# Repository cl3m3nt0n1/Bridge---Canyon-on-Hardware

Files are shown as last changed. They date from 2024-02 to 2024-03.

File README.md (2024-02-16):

# Bridge---Canyon-on-Hardware
Welcome to Bridge, the hardware adaptation of Canyon, a convolution reverb plugin. This project utilizes ELK Audio OS and the Raspberry Pi Compute Module 4, featuring three custom-designed boards (1 main board and 2 IO boards). We created this project as the foundation for a complete OpenSource Audio FX Pedal based on community's resources. 

## Overview
Bridge extends Canyon's convolution reverb into the physical realm, combining the power of ELK Audio OS/HifiBerry DAC+ADC and Raspberry Pi Compute Module 4 for a robust audio FX solution.

## Features
- **Convolution Reverb:** Achieve realistic and immersive reverb effects through Canyon.
- **Custom Hardware:** Three boards - 1 main and 2 IO boards - designed for modularity and reusability.
- **ELK Audio OS:** Leverage the efficiency of ELK Audio OS for real-time audio processing.

## Hardware
Bridge comprises the following custom-designed boards:

1. **Main Board:**
   - GPIO/HAT Connector
   - SPI Screen Connector for a [480*320 ILI9488 based screen]([url](https://www.amazon.fr/gp/product/B08NV6SNYH/ref=ppx_yo_dt_b_asin_title_o00_s00?ie=UTF8&psc=1))
   - Raspberry Pi Compute Module 4
   - ATMega328p with ICSP connector for IO management

2. **IO Boards (x2):**
   - Pots and Switches for massive fun
   - Rotary encoder

## Software
Bridge relies on serveral pieces of sotware to run :
1. **ATMega328p:**
  - Potentiometer values conversion
  - Screen management
  - Serial communication with CM4
2. **Compute Module 4:**
  - Running ELK Audio OS for real-time audio processing
  - IO management
  - OSC
  - Serial Communication with ATMega328p

## Contributing
We welcome and encourage contributions to enhance Bridge! If you have ideas, bug fixes, or new features, please open an issue or submit a pull request.

## License
The software contained in this project is licensed under the GPL3 license. The hardware is licensed under the Creative Commons v4.0.

Happy coding with Bridge!

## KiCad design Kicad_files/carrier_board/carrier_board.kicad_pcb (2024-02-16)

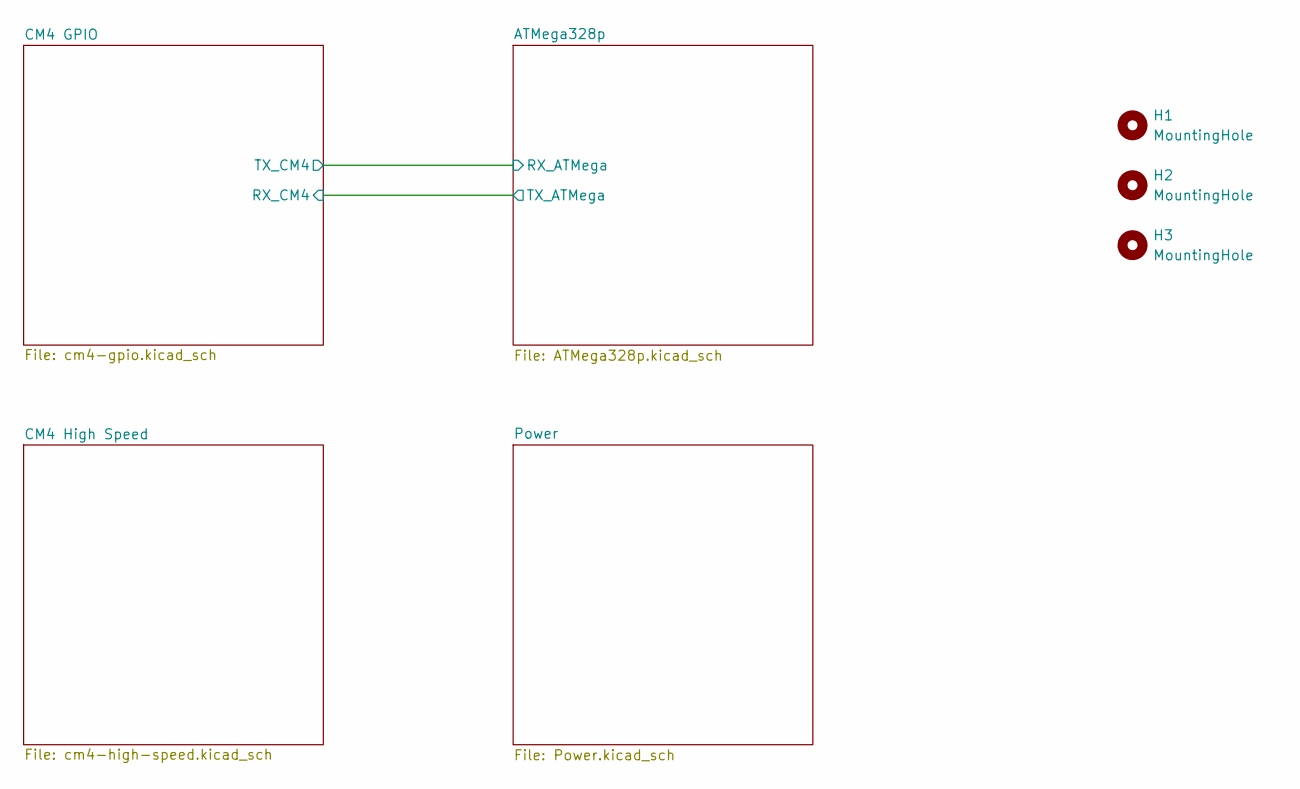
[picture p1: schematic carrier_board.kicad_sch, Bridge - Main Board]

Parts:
H1, H2, H3: MountingHole; MountingHole_2.2mm_M2

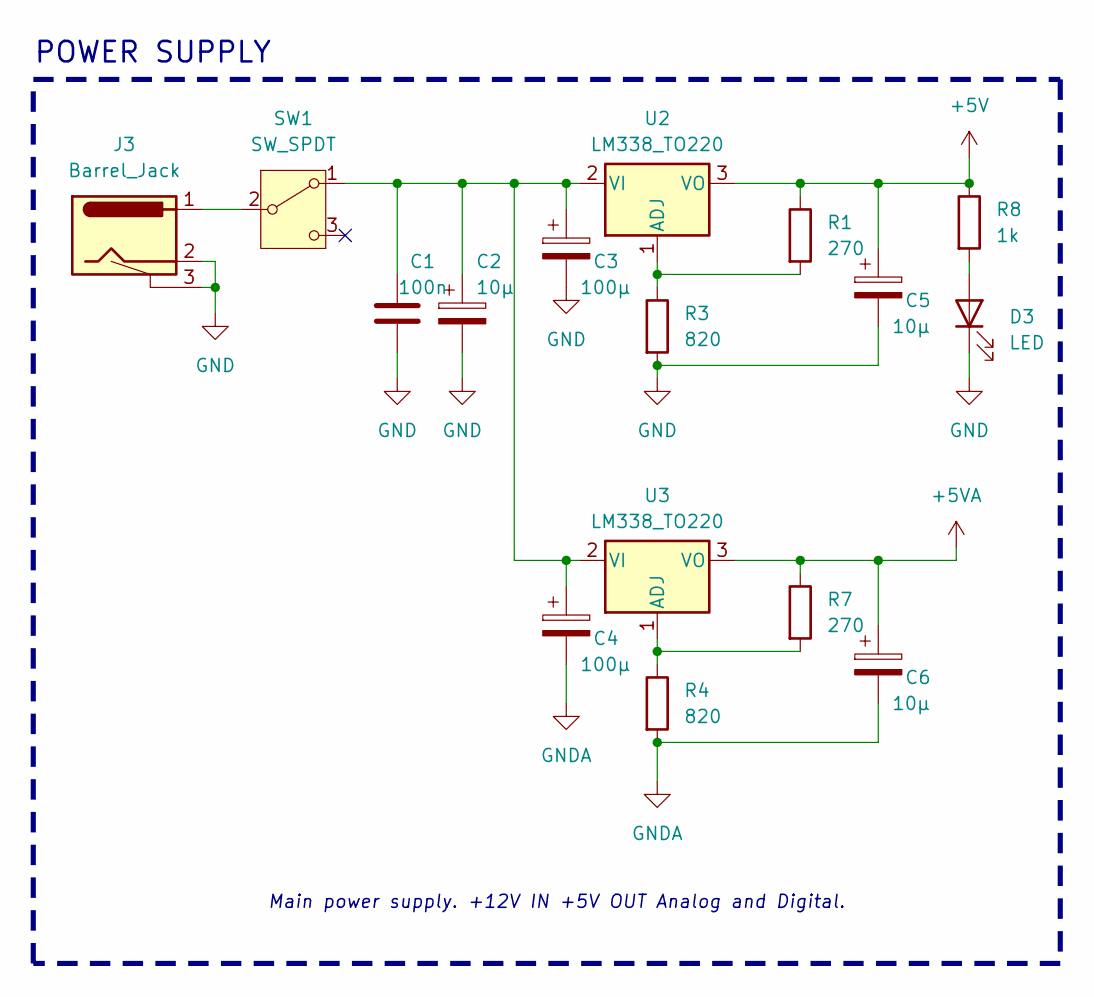
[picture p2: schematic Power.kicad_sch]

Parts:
C1: 100n; C_0402_1005Metric
C2, C5, C6: 10µ; CAPMP3216X180N
C3, C4: 100µ; C_1812_4532Metric
D3: LED; LED_D3.0mm
J3: Barrel_Jack; BarrelJack_Horizontal
R1, R7: 270; R_0603_1608Metric
R3, R4: 820; R_0603_1608Metric
R8: 1k; R_0402_1005Metric
SW1: SW_SPDT; SW_Push_1P2T_Vertical_E-Switch_800UDP8P1A1M6
U2, U3: LM338_TO220; TO-220-3_Vertical

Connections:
+5V: C5.1, R1.1, R8.1, U2.3 (VO); also elsewhere on the board
+5VA: C6.1, R7.1, U3.3 (VO); also elsewhere on the board
GND: C1.2, C2.2, C3.2, C5.2, D3.1 (K), J3.2, J3.3, R3.2; also elsewhere on the board
GNDA: C4.2, C6.2, R4.2; also elsewhere on the board
unnamed: D3.2 (A), R8.2
unnamed: C1.1, C2.1, C3.1, C4.1, SW1.1 (A), U2.2 (VI), U3.2 (VI)
unnamed: J3.1, SW1.2 (B)
unnamed: R1.2, R3.1, U2.1 (ADJ)
unnamed: R4.1, R7.2, U3.1 (ADJ)

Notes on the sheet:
POWER SUPPLY
Main power supply. +12V IN +5V OUT Analog and Digital.

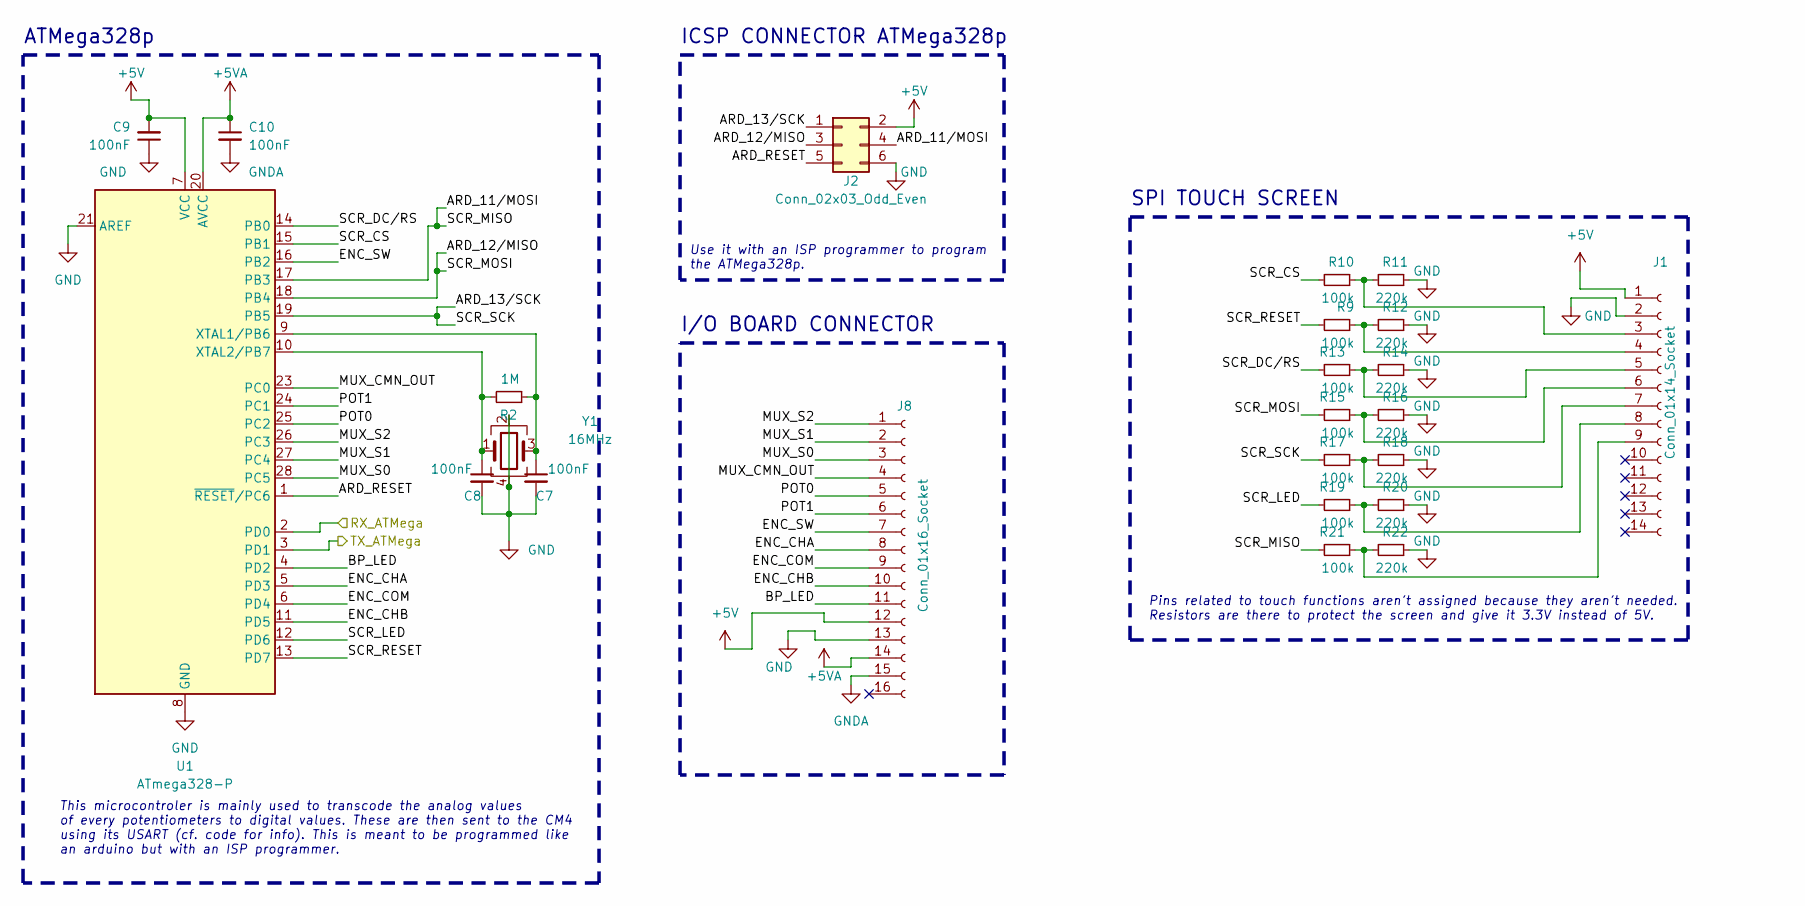
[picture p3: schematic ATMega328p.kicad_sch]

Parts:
C7, C8, C9, C10: 100nF; C_0402_1005Metric
J1: Conn_01x14_Socket; PinSocket_1x14_P2.54mm_Vertical
J2: Conn_02x03_Odd_Even; PinHeader_2x03_P2.00mm_Vertical
J8: Conn_01x16_Socket; Hirose_FH12-16S-0.5SH_1x16-1MP_P0.50mm_Horizontal
R2: 1M; R_0402_1005Metric
R9, R10, R13, R15, R17, R19, R21: 100k; R_0402_1005Metric
R11, R12, R14, R16, R18, R20, R22: 220k; R_0603_1608Metric
U1: ATmega328-P; DIP-28_W7.62mm
Y1: 16MHz; Crystal_SMD_3225-4Pin_3.2x2.5mm

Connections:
+5V: C9.2, J1.1, J2.2, J8.12, U1.7 (VCC); also elsewhere on the board
+5VA: C10.1, J8.14, U1.20 (AVCC); also elsewhere on the board
/ATMega328p/ARD_11/MOSI: J2.4, R21.1, U1.17 (PB3)
/ATMega328p/ARD_12/MISO: J2.3, R15.1, U1.18 (PB4)
/ATMega328p/ARD_13/SCK: J2.1, R17.1, U1.19 (PB5)
/ATMega328p/ARD_RESET: J2.5, U1.1 (~RESET/PC6)
/ATMega328p/BP_LED: J8.11, U1.4 (PD2)
/ATMega328p/ENC_CHA: J8.8, U1.5 (PD3)
/ATMega328p/ENC_CHB: J8.10, U1.11 (PD5)
/ATMega328p/ENC_COM: J8.9, U1.6 (PD4)
/ATMega328p/ENC_SW: J8.7, U1.16 (PB2)
/ATMega328p/MUX_CMN_OUT: J8.4, U1.23 (PC0)
/ATMega328p/MUX_S0: J8.3, U1.28 (PC5)
/ATMega328p/MUX_S1: J8.2, U1.27 (PC4)
/ATMega328p/MUX_S2: J8.1, U1.26 (PC3)
/ATMega328p/POT0: J8.5, U1.25 (PC2)
/ATMega328p/POT1: J8.6, U1.24 (PC1)
/ATMega328p/SCR_CS: R10.1, U1.15 (PB1)
/ATMega328p/SCR_DC/RS: R13.1, U1.14 (PB0)
/ATMega328p/SCR_LED: R19.1, U1.12 (PD6)
/ATMega328p/SCR_RESET: R9.1, U1.13 (PD7)
/CM4 GPIO/GPIO14: U1.2 (PD0); also elsewhere on the board
/CM4 GPIO/GPIO15: U1.3 (PD1); also elsewhere on the board
GND: C7.2, C8.2, C9.1, J1.2, J2.6, J8.13, R11.2, R12.2, R14.2, R16.2, R18.2, R20.2, R22.2, U1.8 (GND), U1.21 (AREF), U1.22 (GND), Y1.2, Y1.4; also elsewhere on the board
GNDA: C10.2, J8.15; also elsewhere on the board
unnamed: J1.3, R10.2, R11.1
unnamed: J1.4, R9.2, R12.1
unnamed: J1.5, R13.2, R14.1
unnamed: J1.6, R15.2, R16.1
unnamed: J1.7, R17.2, R18.1
unnamed: J1.8, R19.2, R20.1
unnamed: J1.9, R21.2, R22.1
unnamed: C7.1, R2.1, U1.9 (XTAL1/PB6), Y1.3
unnamed: C8.1, R2.2, U1.10 (XTAL2/PB7), Y1.1

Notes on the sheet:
I/O BOARD CONNECTOR
This microcontroler is mainly used to transcode the analog values of every potentiometers to digital values. These are then sent to the CM4 using its USART (cf. code for info). This is meant to be programmed like an arduino but with an ISP programmer.
Use it with an ISP programmer to program the ATMega328p.
SPI TOUCH SCREEN
ICSP CONNECTOR ATMega328p
ATMega328p
Pins related to touch functions aren't assigned because they aren't needed. Resistors are there to protect the screen and give it 3.3V instead of 5V.

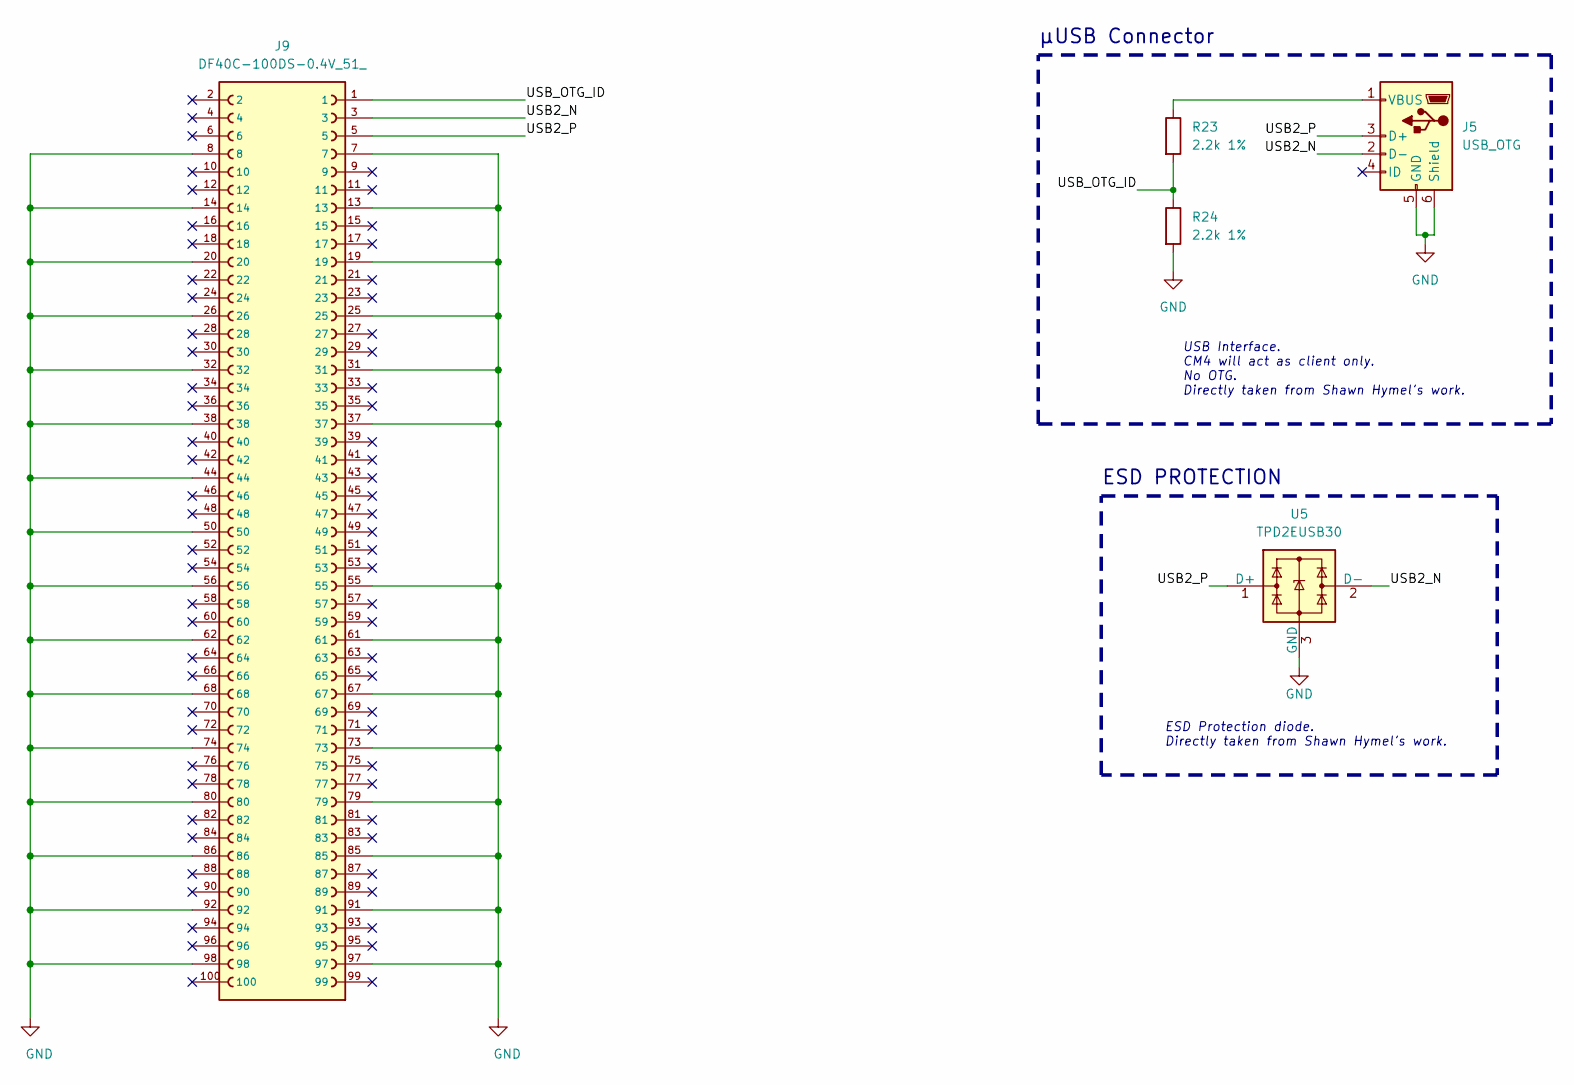
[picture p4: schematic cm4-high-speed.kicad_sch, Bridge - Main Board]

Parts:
J5: USB_OTG; USB_Micro-B_EDAC_UCON00686
J9: DF40C-100DS-0.4V_51_; HIROSE_DF40C-100DS-0.4V_51_; PARTREV Oct.1.2023
R23, R24: 2.2k 1%; R_0402_1005Metric
U5: TPD2EUSB30; Texas_DRT-3

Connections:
/CM4 High Speed/USB2_N: J5.2 (D-), J9.3, U5.2 (D-)
/CM4 High Speed/USB2_P: J5.3 (D+), J9.5, U5.1 (D+)
/CM4 High Speed/USB_OTG_ID: J9.1, R23.2, R24.1
GND: J5.5 (GND), J5.6 (Shield), J9.7, J9.8, J9.13, J9.14, J9.19, J9.20, J9.25, J9.26, J9.31, J9.32, J9.37, J9.38, J9.44, J9.50, J9.55, J9.56, J9.61, J9.62, J9.67, J9.68, J9.73, J9.74, J9.79, J9.80, J9.85, J9.86, J9.91, J9.92, J9.97, J9.98, R24.2, U5.3 (GND); also elsewhere on the board
unnamed: J5.1 (VBUS), R23.1

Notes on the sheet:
µUSB Connector
ESD PROTECTION
USB Interface. CM4 will act as client only. No OTG. Directly taken from Shawn Hymel's work.
ESD Protection diode. Directly taken from Shawn Hymel's work.

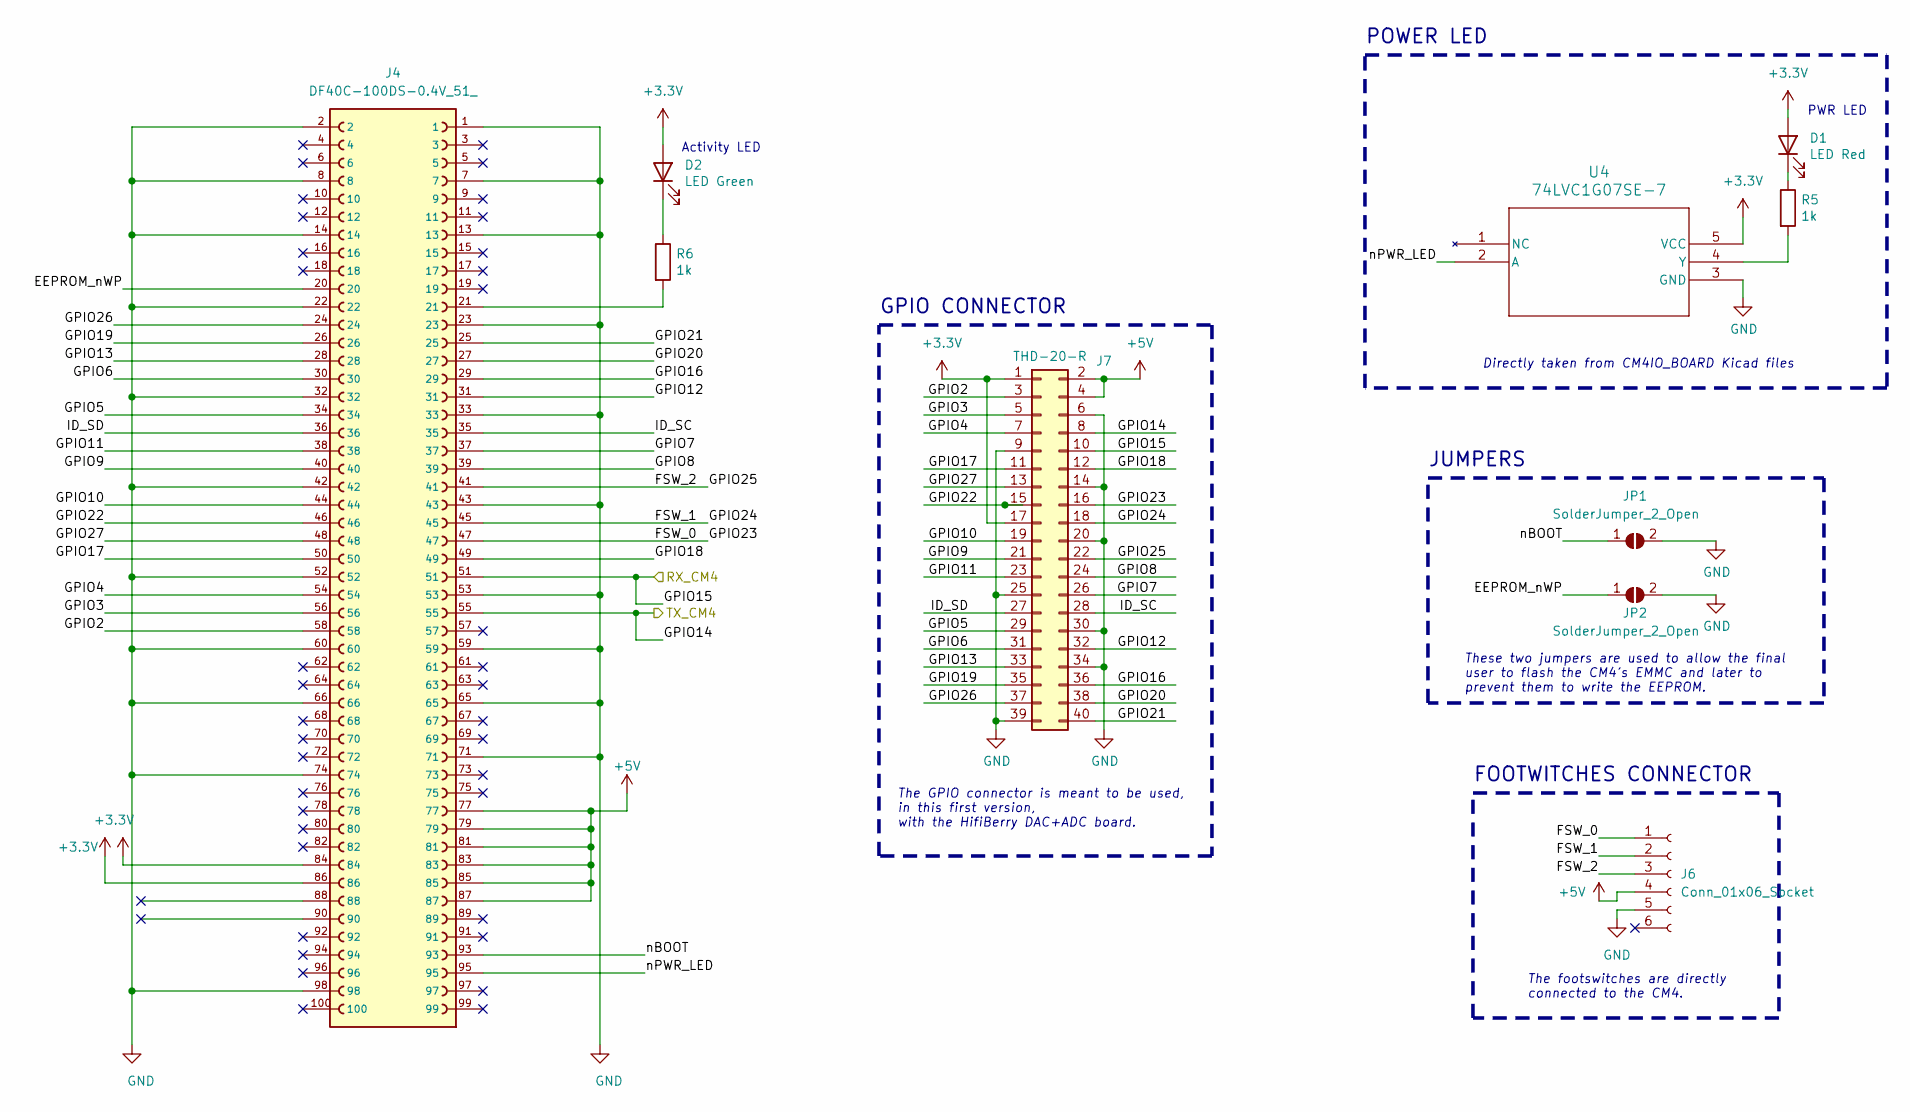
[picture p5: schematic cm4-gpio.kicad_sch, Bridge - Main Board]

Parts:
D1: LED Red; LED_0603_1608Metric; Part Description Red 620nm LED Indication - Discrete 2.2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
D2: LED Green; LED_0603_1608Metric; Part Description Green 572nm LED Indication - Discrete 2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
J4: DF40C-100DS-0.4V_51_; HIROSE_DF40C-100DS-0.4V_51_; PARTREV Oct.1.2023
J6: Conn_01x06_Socket; Hirose_FH12-6S-0.5SH_1x06-1MP_P0.50mm_Horizontal
J7: THD-20-R; PinHeader_2x20_P2.54mm_Vertical; Part Description PinHeader_2x20_P2.54mm_Vertical
JP1, JP2: SolderJumper_2_Open; PinHeader_1x02_P2.00mm_Vertical
R5, R6: 1k; R_0402_1005Metric; Part Description Resistor 1K M1005 1% 63mW
U4: 74LVC1G07SE-7; SOT353_DIO

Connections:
+3.3V: D1.2 (A), D2.2 (A), J4.84, J4.86, J7.1, J7.17, U4.5 (VCC)
+5V: J4.77, J4.79, J4.81, J4.83, J4.85, J4.87, J6.4, J7.2, J7.4; also elsewhere on the board
/CM4 GPIO/EEPROM_nWP: J4.20, JP2.1 (A)
/CM4 GPIO/FSW_0: J4.47, J6.1, J7.16
/CM4 GPIO/FSW_1: J4.45, J6.2, J7.18
/CM4 GPIO/FSW_2: J4.41, J6.3, J7.22
/CM4 GPIO/GPIO2: J4.58, J7.3
/CM4 GPIO/GPIO3: J4.56, J7.5
/CM4 GPIO/GPIO4: J4.54, J7.7
/CM4 GPIO/GPIO5: J4.34, J7.29
/CM4 GPIO/GPIO6: J4.30, J7.31
/CM4 GPIO/GPIO7: J4.37, J7.26
/CM4 GPIO/GPIO8: J4.39, J7.24
/CM4 GPIO/GPIO9: J4.40, J7.21
/CM4 GPIO/GPIO10: J4.44, J7.19
/CM4 GPIO/GPIO11: J4.38, J7.23
/CM4 GPIO/GPIO12: J4.31, J7.32
/CM4 GPIO/GPIO13: J4.28, J7.33
/CM4 GPIO/GPIO14: J4.55, J7.8; also elsewhere on the board
/CM4 GPIO/GPIO15: J4.51, J7.10; also elsewhere on the board
/CM4 GPIO/GPIO16: J4.29, J7.36
/CM4 GPIO/GPIO17: J4.50, J7.11
/CM4 GPIO/GPIO18: J4.49, J7.12
/CM4 GPIO/GPIO19: J4.26, J7.35
/CM4 GPIO/GPIO20: J4.27, J7.38
/CM4 GPIO/GPIO21: J4.25, J7.40
/CM4 GPIO/GPIO22: J4.46, J7.15
/CM4 GPIO/GPIO26: J4.24, J7.37
/CM4 GPIO/GPIO27: J4.48, J7.13
/CM4 GPIO/ID_SC: J4.35, J7.28
/CM4 GPIO/ID_SD: J4.36, J7.27
/CM4 GPIO/nBOOT: J4.93, JP1.1 (A)
/CM4 GPIO/nPWR_LED: J4.95, U4.2 (A)
GND: J4.1, J4.2, J4.7, J4.8, J4.13, J4.14, J4.22, J4.23, J4.32, J4.33, J4.42, J4.43, J4.52, J4.53, J4.59, J4.60, J4.65, J4.66, J4.71, J4.74, J4.98, J6.5, J7.6, J7.9, J7.14, J7.20, J7.25, J7.30, J7.34, J7.39, JP1.2 (B), JP2.2 (B), U4.3 (GND); also elsewhere on the board
unnamed: D1.1 (K), R5.1
unnamed: D2.1 (K), R6.1
unnamed: J4.21, R6.2
unnamed: R5.2, U4.4 (Y)

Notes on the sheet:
The footswitches are directly connected to the CM4.
FOOTWITCHES CONNECTOR
JUMPERS
POWER LED
PWR LED
Activity LED
These two jumpers are used to allow the final user to flash the CM4's EMMC and later to prevent them to write the EEPROM.
The GPIO connector is meant to be used, in this first version, with the HifiBerry DAC+ADC board.
GPIO CONNECTOR
Directly taken from CM4IO_BOARD Kicad files

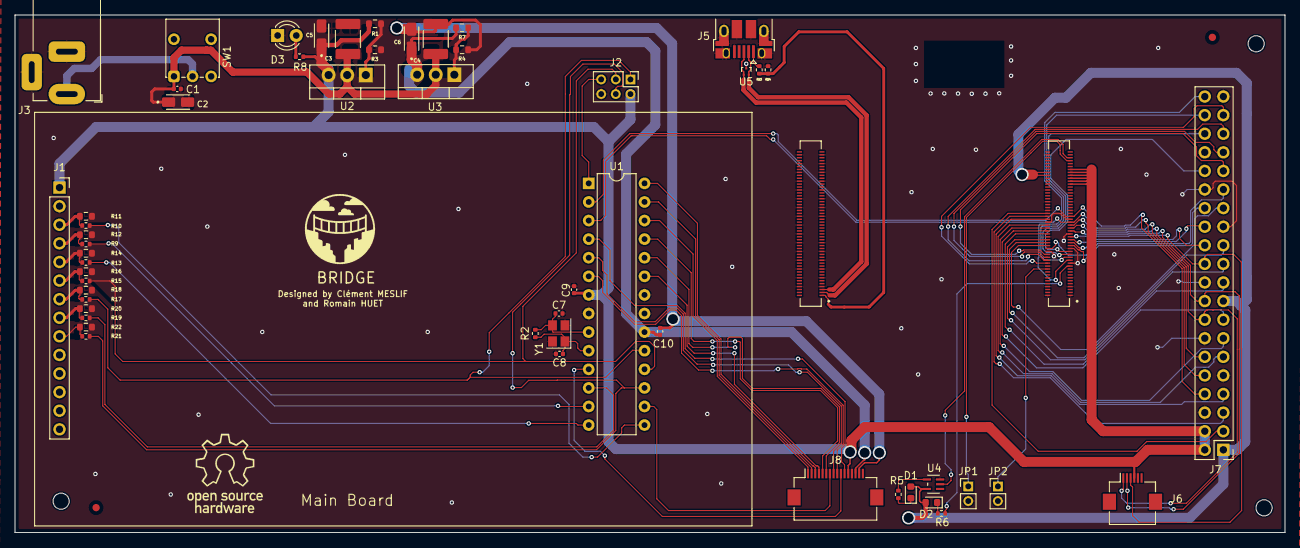
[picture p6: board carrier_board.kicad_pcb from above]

Board: 4 copper layers, 173.5 x 70.7 mm, 58 parts (0 on the bottom side), 77 nets.

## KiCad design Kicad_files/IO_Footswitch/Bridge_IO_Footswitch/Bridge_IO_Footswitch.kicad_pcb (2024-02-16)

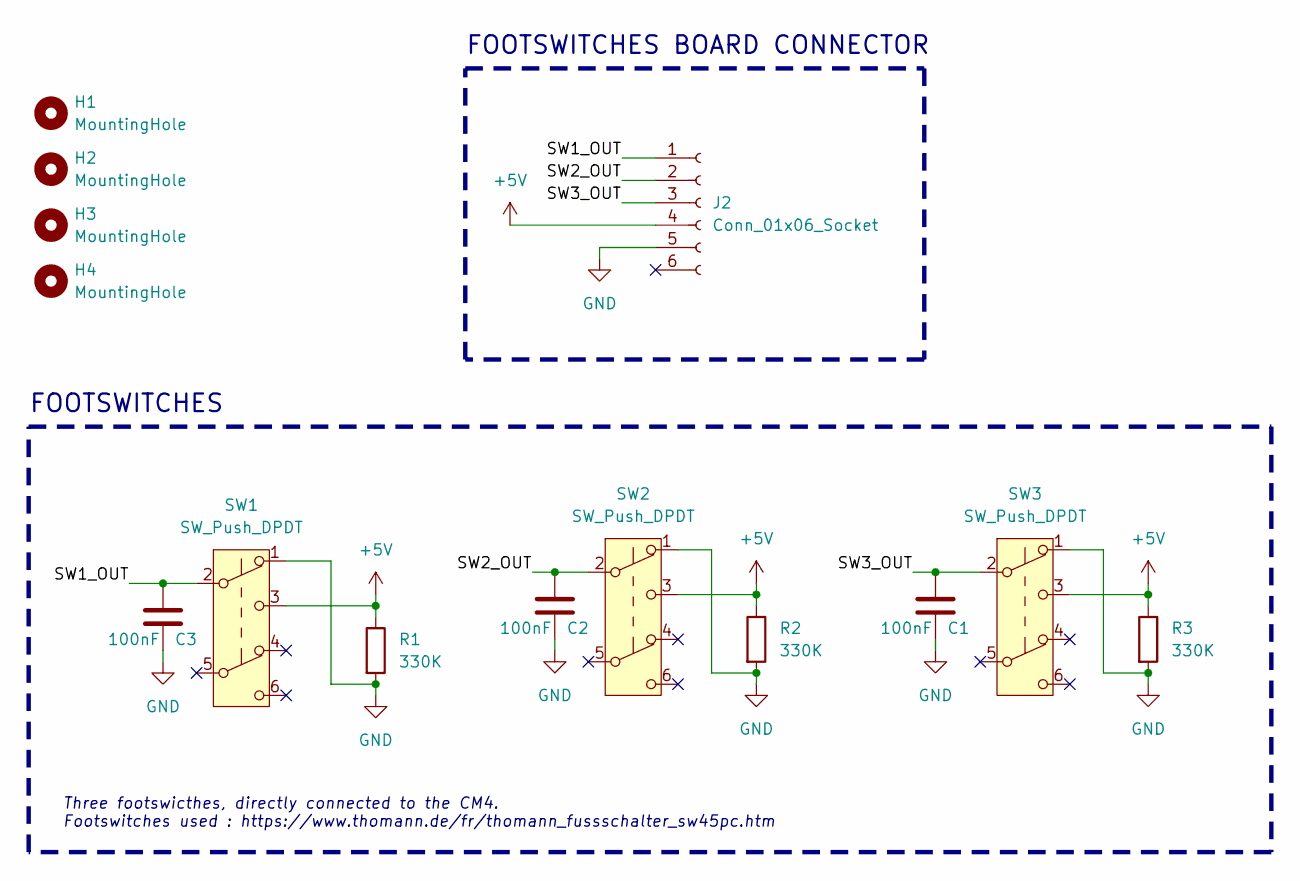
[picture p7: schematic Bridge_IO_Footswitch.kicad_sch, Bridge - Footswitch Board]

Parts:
C1, C2, C3: 100nF; C_0402_1005Metric
H1, H2, H3, H4: MountingHole; MountingHole_2.2mm_M2
J2: Conn_01x06_Socket; Hirose_FH12-6S-0.5SH_1x06-1MP_P0.50mm_Horizontal
R1, R2, R3: 330K; R_0603_1608Metric
SW1, SW2, SW3: SW_Push_DPDT; Switch 2 DPDT

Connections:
+5V: J2.4, R1.1, R2.1, R3.1, SW1.3 (C), SW2.3 (C), SW3.3 (C)
/SW1_OUT: C3.1, J2.1, SW1.2 (B)
/SW2_OUT: C2.1, J2.2, SW2.2 (B)
/SW3_OUT: C1.1, J2.3, SW3.2 (B)
GND: C1.2, C2.2, C3.2, J2.5, R1.2, R2.2, R3.2, SW1.1 (A), SW2.1 (A), SW3.1 (A)

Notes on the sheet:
FOOTSWITCHES BOARD CONNECTOR
Three footswicthes, directly connected to the CM4. Footswitches used : https://www.thomann.de/fr/thomann_fussschalter_sw45pc.htm
FOOTSWITCHES

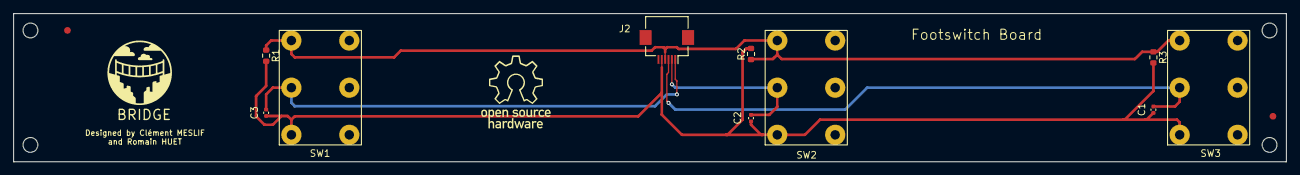
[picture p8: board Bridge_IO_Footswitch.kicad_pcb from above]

Board: 4 copper layers, 189.0 x 22.0 mm, 14 parts (0 on the bottom side), 5 nets.

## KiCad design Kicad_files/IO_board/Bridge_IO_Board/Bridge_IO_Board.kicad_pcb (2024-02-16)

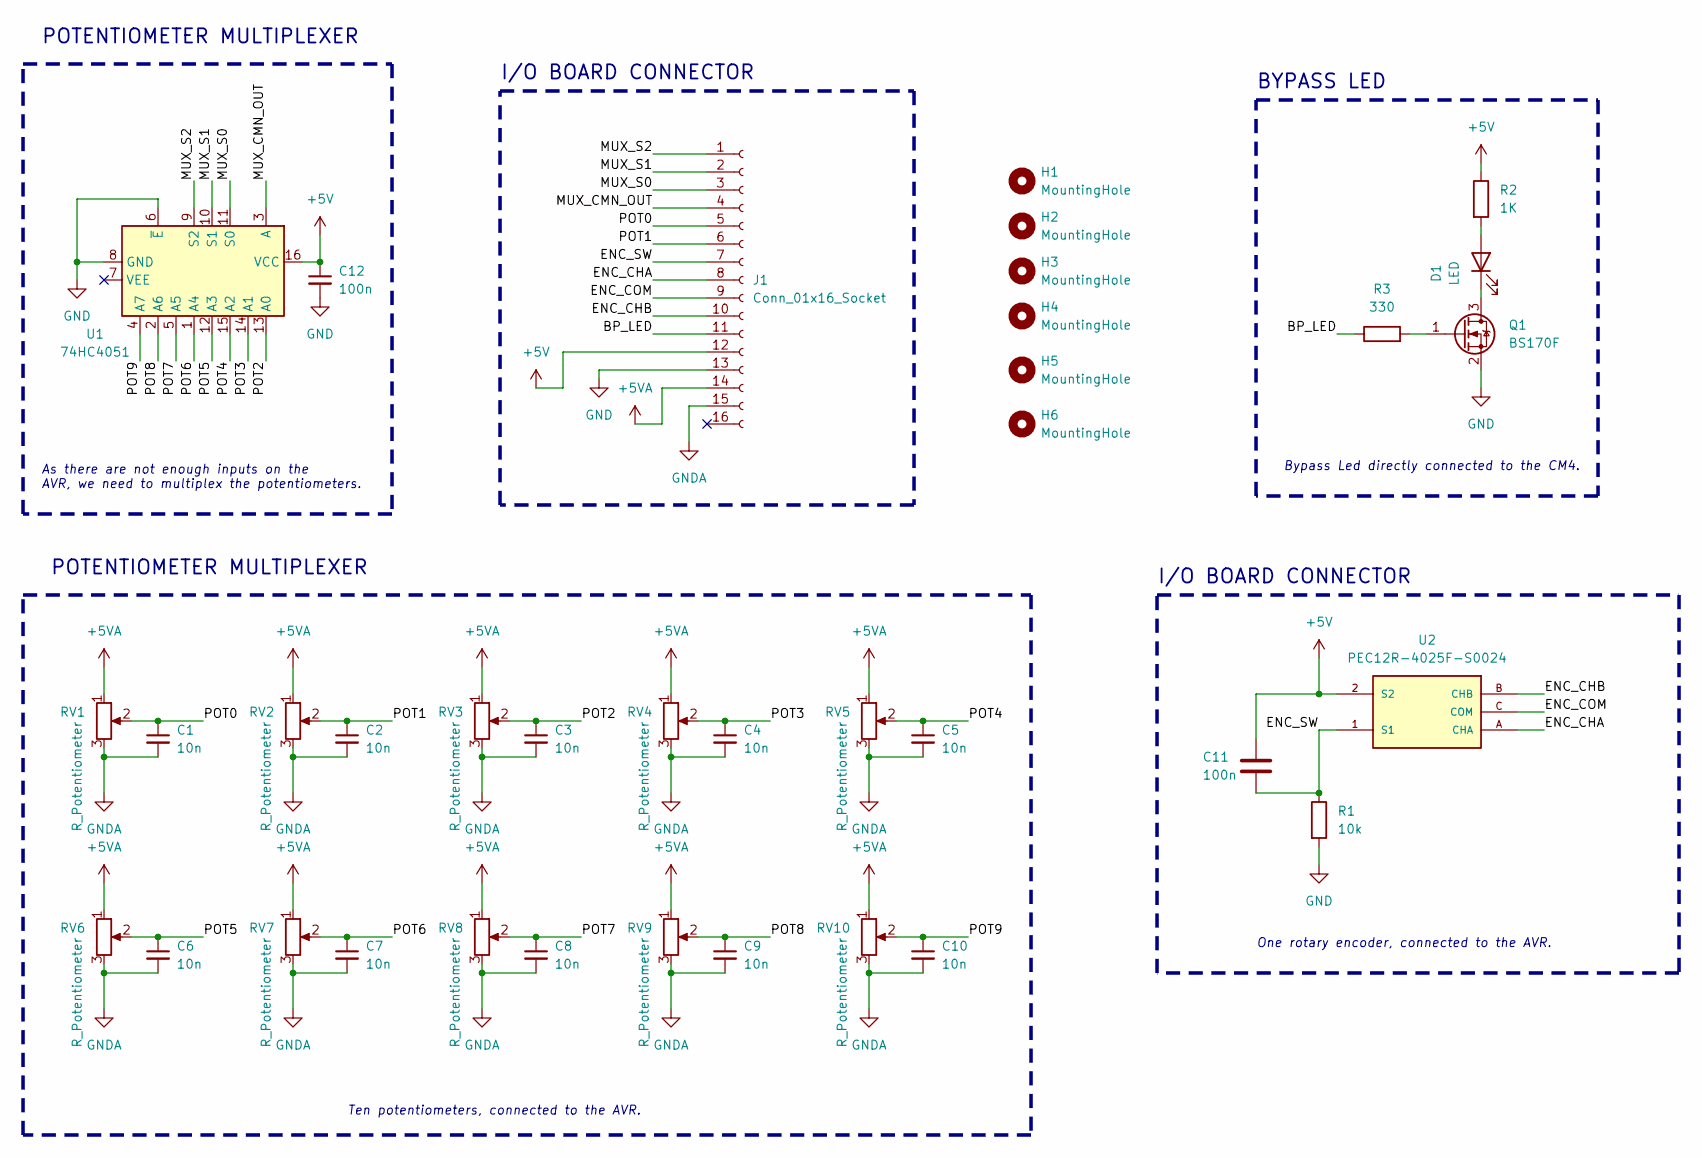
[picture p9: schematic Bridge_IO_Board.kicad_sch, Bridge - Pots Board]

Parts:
C1, C2, C3, C4, C5, C6, C7, C8, C9, C10: 10n; C_0402_1005Metric
C11, C12: 100n; C_0402_1005Metric
D1: LED; LED_D5.0mm
H1, H2, H3, H4, H5, H6: MountingHole; MountingHole_2.2mm_M2
J1: Conn_01x16_Socket; Hirose_FH12-16S-0.5SH_1x16-1MP_P0.50mm_Horizontal
Q1: BS170F; SOT-23
R1: 10k; R_0402_1005Metric
R2: 1K; R_0402_1005Metric
R3: 330; R_0402_1005Metric
RV1, RV2, RV3, RV4, RV5, RV6, RV7, RV8, RV9, RV10: R_Potentiometer; TRIM_R0904NB10KL-25KQ
U1: 74HC4051; DIP-16_W10.16mm_LongPads
U2: PEC12R-4025F-S0024; ENC_PEC12R-4025F-S0024

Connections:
+5V: C11.1, C12.1, J1.12, R2.1, U1.16 (VCC), U2.2 (S2)
+5VA: J1.14, RV1.1, RV2.1, RV3.1, RV4.1, RV5.1, RV6.1, RV7.1, RV8.1, RV9.1, RV10.1
/BP_LED: J1.11, R3.1
/ENC_CHA: J1.8, U2.A (CHA)
/ENC_CHB: J1.10, U2.B (CHB)
/ENC_COM: J1.9, U2.C (COM)
/ENC_SW: C11.2, J1.7, R1.1, U2.1 (S1)
/MUX_CMN_OUT: J1.4, U1.3 (A)
/MUX_S0: J1.3, U1.11 (S0)
/MUX_S1: J1.2, U1.10 (S1)
/MUX_S2: J1.1, U1.9 (S2)
/POT0: C1.1, J1.5, RV1.2
/POT1: C2.1, J1.6, RV2.2
/POT2: C3.1, RV3.2, U1.13 (A0)
/POT3: C4.1, RV4.2, U1.14 (A1)
/POT4: C5.1, RV5.2, U1.15 (A2)
/POT5: C6.1, RV6.2, U1.12 (A3)
/POT6: C7.1, RV7.2, U1.1 (A4)
/POT7: C8.1, RV8.2, U1.5 (A5)
/POT8: C9.1, RV9.2, U1.2 (A6)
/POT9: C10.1, RV10.2, U1.4 (A7)
GND: C12.2, J1.13, Q1.2 (S), R1.2, U1.6 (~E), U1.8 (GND)
GNDA: C1.2, C2.2, C3.2, C4.2, C5.2, C6.2, C7.2, C8.2, C9.2, C10.2, J1.15, RV1.3, RV2.3, RV3.3, RV4.3, RV5.3, RV6.3, RV7.3, RV8.3, RV9.3, RV10.3
unnamed: D1.2 (A), R2.2
unnamed: D1.1 (K), Q1.3 (D)
unnamed: Q1.1 (G), R3.2

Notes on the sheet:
One rotary encoder, connected to the AVR.
POTENTIOMETER MULTIPLEXER
As there are not enough inputs on the AVR, we need to multiplex the potentiometers.
BYPASS LED
Ten potentiometers, connected to the AVR.
Bypass Led directly connected to the CM4.
I/O BOARD CONNECTOR

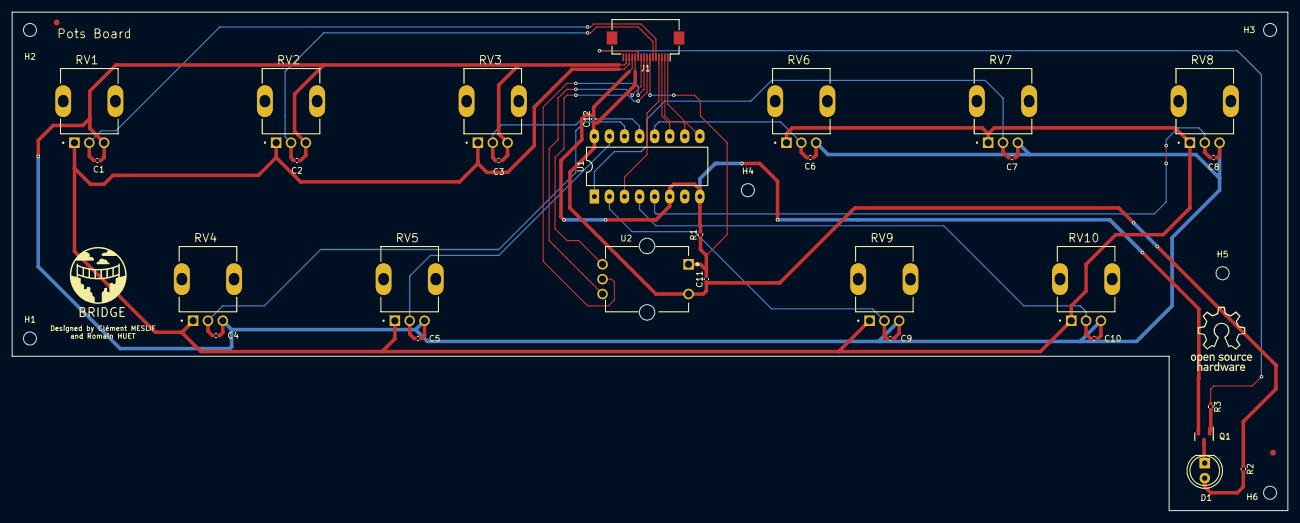
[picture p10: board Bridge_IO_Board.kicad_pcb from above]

Board: 4 copper layers, 215.0 x 84.0 mm, 36 parts (0 on the bottom side), 26 nets.

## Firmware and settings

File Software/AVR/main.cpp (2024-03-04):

/*
 * Authors : @Cl3m3nt0n1 - @RomainH27
 * Licence : GPL3
 */
#include <Arduino.h>

// Define addresses for each potentiometer
#define POT1_ADDR 1
#define POT2_ADDR 2
#define POT3_ADDR 3
#define POT4_ADDR 4
#define POT5_ADDR 5
#define POT6_ADDR 6
const char* specialString = "READY?";


// Variables to store potentiometer values
int pot1Val = 0;
int pot2Val = 0;
int pot3Val = 0;
int pot4Val = 0;
int pot5Val = 0;
int pot6Val = 0;

// Analog pin assignments for each potentiometer
unsigned char pot1 = A0;
unsigned char pot2 = A1;
unsigned char pot3 = A2;
unsigned char pot4 = A3;
unsigned char pot5 = A4;
unsigned char pot6 = A5;


/**
 * @brief Prepares a string representation of a potentiometer value.
 *
 * This function takes the analog pin address of a potentiometer, reads its
 * value, and creates a formatted string to represent the address and value.
 *
 * @param potAddr The analog pin address of the potentiometer.
 * @return A formatted string containing the address and value.
 */
String preparePot(unsigned char potAddr)
{
    String stringToPrint = "@";
    switch (potAddr)
    {
    case A0:
        stringToPrint += POT1_ADDR;
        stringToPrint += "/";
        stringToPrint += pot1Val;
        return stringToPrint;
        break;

    case A1:
        stringToPrint += POT2_ADDR;
        stringToPrint += "/";
        stringToPrint += pot2Val;
        return stringToPrint;
        break;

    case A2:
        stringToPrint += POT3_ADDR;
        stringToPrint += "/";
        stringToPrint += pot3Val;
        return stringToPrint;
        break;

    case A3:
        stringToPrint += POT4_ADDR;
        stringToPrint += "/";
        stringToPrint += pot4Val;
        return stringToPrint;
        break;

    case A4:
        stringToPrint += POT5_ADDR;
        stringToPrint += "/";
        stringToPrint += pot5Val;
        return stringToPrint;
        break;

    case A5:
        stringToPrint += POT6_ADDR;
        stringToPrint += "/";
        stringToPrint += pot6Val;
        return stringToPrint;
        break;

    default:
        return "";
        break;
    }
}

/**
 * @brief Initializes the timer for periodic interrupt handling.
 *
 * This function configures Timer1 with a prescaler and initial counter value
 * to generate periodic interrupts for handling potentiometer readings.
 * Period = 10ms
 */
void initTimer()
{
    TCCR1A = 0;          // Init Timer1A
    TCCR1B = 0;          // Init Timer1B
    TCCR1B |= B00000010; // Prescaler = 8
    TCNT1 = 45535;       // Timer Preloading
    TIMSK1 |= B00000001; // Enable Timer Overflow Interrupt
}

/**
 * @brief Handles the timer interrupt to read potentiometer values and send them via UART.
 *
 * This function is called whenever the timer overflows, and it reads the values of all
 * potentiometers and sends them via UART (Serial).
 */
void handleInterrupt()
{
    // Get values from all potentiometers
    pot1Val = analogRead(pot1);
    pot2Val = analogRead(pot2);
    pot3Val = analogRead(pot3);
    pot4Val = analogRead(pot4);
    pot5Val = analogRead(pot5);
    pot6Val = analogRead(pot6);

    // Send data to UART
    Serial.println(preparePot(pot1));
    Serial.println(preparePot(pot2));
    Serial.println(preparePot(pot3));
    Serial.println(preparePot(pot4));
    Serial.println(preparePot(pot5));
    Serial.println(preparePot(pot6));
}

/**
 * @brief Negotiation function.
 *
 * This function wait for inputs on Serial port.
 * If input is 'OK', initiate the communication and
 * begin to send Pots values.
 */
unsigned char negotiate()
{
    if (Serial.available() >  0) { 
    String receivedString = Serial.readStringUntil('\n'); 
    receivedString.trim();
    if (receivedString == specialString) {
      delay(1200);
      Serial.println("OK");
      delay(1000);
      return 1; 
    }
    else
      return 0;
  }
}

/**
 * @brief Setup function called once at the beginning of the program.
 *
 * This function initializes Serial communication, sets up the timer, and enables interrupts.
 */
void setup()
{

    Serial.begin(115200);
    while(!negotiate());
    initTimer();

    // Enable global interrupts
    interrupts();

}

/**
 * @brief Loop function called repeatedly in the main program.
 *
 * This function is intentionally left empty as all operations are handled in the timer interrupt.
 */
void loop() {}

/**
 * @brief Timer1 Overflow Interrupt Service Routine.
 *
 * This function is called whenever Timer1 overflows, triggering the periodic
 * reading and sending of potentiometer values.
 */
ISR(TIMER1_OVF_vect)
{
    TCNT1 = 45535; // Timer Preloading
    // Handle The Timer Overflow Interrupt
    handleInterrupt();
}

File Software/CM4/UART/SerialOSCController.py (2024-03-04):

"""
SerialOSCController - Serial to OSC Communication Controller

Authors : @Cl3m3nt0n1 - @RomainH27
Licence : GPL3

This class reads data from a serial port, smoothens it, and sends OSC messages
to sushi based on the read addresses and values.
Any received message must be written like so : @address/integer_converted_value_of_a_pot


Attributes:
    - serial_port (str): The serial port from which to read data (default: '/dev/ttyS0').
    - osc_ip (str): The IP address of the OSC server to which to send messages (default: '127.0.0.1').
    - osc_port (int): The port of the OSC server to which to send messages (default: 24024).
    - smoothing_factor (float): The smoothing factor to smooth the read values (default: 0.2).
    - max_smoothed_values (int): The maximum number of smoothed values to retain (default: 10).
    - debug (bool): Enable debug mode to display additional information (default: False).

Methods:
    - __init__(self, serial_port, osc_ip, osc_port, smoothing_factor=0.2, max_smoothed_values=10, debug=False):
        Initializes a new instance of SerialOSCController.

    - process_serial_data(self):
        Reads data from the serial port, smoothes it, and sends OSC messages based on the read addresses and values.

    - is_variation_sufficient(self, address, smoothed_value):
        Checks if the variation between the new smoothed value and the previous one is significant enough to emit an OSC message.

    - route_osc_message(self, address, value):
        Routes OSC messages based on the read address.

    - send_osc_message(self, address, value):
        Sends an OSC message to the specified address with the specified value.

    - run(self):
        Executes the main loop to continuously read and process serial data.

"""
import RPi.GPIO as GPIO
from pythonosc import udp_client
import serial
import time

class SerialOSCController:
    def __init__(self, serial_port, osc_ip, osc_port, smoothing_factor=0.2, max_smoothed_values=10, debug=False):
        self.ser = serial.Serial(serial_port, 115200, timeout=1)
        self.ser.reset_input_buffer()
        self.osc_client = udp_client.SimpleUDPClient(osc_ip, osc_port)
        self.smoothing_factor = smoothing_factor
        self.max_smoothed_values = max_smoothed_values
        self.smoothed_values = {}
        self.debug = debug


    def send_osc_message(self, address, value):
        self.osc_client.send_message(address, value)


    def process_serial_data(self):
        if self.ser.in_waiting > 0:
            line = self.ser.readline().decode('utf-8').rstrip()
            address, raw_value = line.split('/')
            raw_value = int(raw_value)

            if address not in self.smoothed_values:
                self.smoothed_values[address] = [raw_value]
            else:
                # Adds a new value to list
                self.smoothed_values[address].append(raw_value)

                # Smoothing the incoming value
                smoothed_value = sum(self.smoothed_values[address]) / len(self.smoothed_values[address])

                # Going Low on RAM here
                self.smoothed_values[address] = self.smoothed_values[address][-self.max_smoothed_values:]

                if self.is_variation_sufficient(address, smoothed_value):
                    value = round(smoothed_value / 1024, 2)
                    self.route_osc_message(address, value)
                    if self.debug:
                        print("message sent : ", address, value) # DBG Only


    def is_variation_sufficient(self, address, smoothed_value):
        threshold = 1.2
        
        # Adds any previously unseen value
        if address not in self.smoothed_values or len(self.smoothed_values[address]) < 2:
            return True

        # Comparison with previous value
        previous_smoothed_value = self.smoothed_values[address][-2]
        variation = abs(smoothed_value - previous_smoothed_value)

        return variation > threshold


    def route_osc_message(self, address, value):
        if address == '@1':
            self.send_osc_message("/parameter/Canyon/Dry_Wet", value)
        elif address == '@2':
            self.send_osc_message("/parameter/Canyon/Gain", value)
        elif address == '@3':
            self.send_osc_message("/parameter/Canyon/Blend", value)
        elif address == '@4':
            self.send_osc_message("/parameter/Canyon/HighCut_Freq", value)
        elif address == '@5':
            self.send_osc_message("/parameter/Canyon/HighCut_FreqB", value)
        elif address == '@6':
            self.send_osc_message("/parameter/Canyon/LowCut_Freq", value)

    def negociate(self, serial_port):
        # Is arduino ready ?
        self.ser.write(b"READY?\n")
        self.ser.flush()
        time.sleep(1)

        # Hope it answers in less than 5 seconds
        start_time = time.time()
        timeout =  5  # Timeout in seconds
        while time.time() - start_time < timeout:
            if serial_port.in_waiting >  0:
                response = self.ser.readline().decode('utf-8').rstrip()
                print(response)
                if response == "OK":
                    return  # it's ready so, let's go
                else:
                    raise Exception("Unexpected response from the other device.")
            time.sleep(0.1)

        # Timeout reached, no answers...
        raise Exception("Negotiation timed out. The other device did not respond.")


    def run(self):
        self.negociate(self.ser)
        while True:
            self.process_serial_data()

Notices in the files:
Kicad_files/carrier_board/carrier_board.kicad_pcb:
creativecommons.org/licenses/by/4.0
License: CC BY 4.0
